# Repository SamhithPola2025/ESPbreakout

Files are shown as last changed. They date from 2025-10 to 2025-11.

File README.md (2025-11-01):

# ESPbreakout
## Overview
ESPbreakout is a breakout board for the popular ESP32-s3  chip that includes many breakout pins, compatible with any other ESP32 setup (for the most part), and has programming via USB 2.0.
This board uses the ESP32-S3 SOC, which means that it does not use any of the modules that espressif has already made, and just the bare ESP32-S3 chip.
This board includes pins for progamming, a USB-C port (for programming & power), a screw terminal to convenient wire up a Lithium battery to (3.7v). And you can also utilize the PSRAM that I added externally onto the board. The board includes comprehensive labels for buttons and pins, for ease of use. The cost and materials used to manafacture/make this board are in the BOM.csv file.

## Intent behind making this board:
I made this board to showcase what I already know, and to learn a lot of new things (I can say that this one was accomplished). I also made this board to act as a substitute for the ESP32-S3 devboard that exists, and of course it wont be better than the board made by the actual company, Espressif, but it will be pretty decent and working!

## Pictures



(Pictures of the built version will be added once I get all the components and solder what needs to be soldered, for the most part this is PCBA though.)

| Reference | Quantity | Part | Unit Price | Extended Price |
| --- | --- | --- | --- | --- |
| PCBA | 1 | PCBA Estimate | $52.55 | $52.55 |
| B1 | 1 | TinyCircuits BATTERY LITH-ION 3.7V 1AH | $9.95 | $9.95 |
| C1 | 1 | Pololu 2PIN F JST PH-STYLE CABLE 12CM | $1.47 | $1.47 |
| J1 | 3 | Sullins Connector Solutions CONN HDR 4POS 0.1 GOLD PCB | $0.38 | $1.14 |
| J2 | 1 | Phoenix Contact TERM BLK 2POS SIDE ENTRY 5MM PCB | $0.78 | $0.78 |
| **Total** | | | | **$71.89** |

Note: $6.00 of buffer is added for shipping or tariff changes. Any unused buffer will be returned.

## Cart screenshots
Screenshot 2025-11-01 at 11 53 29 AM
Screenshot 2025-11-01 at 12 08 29 PM

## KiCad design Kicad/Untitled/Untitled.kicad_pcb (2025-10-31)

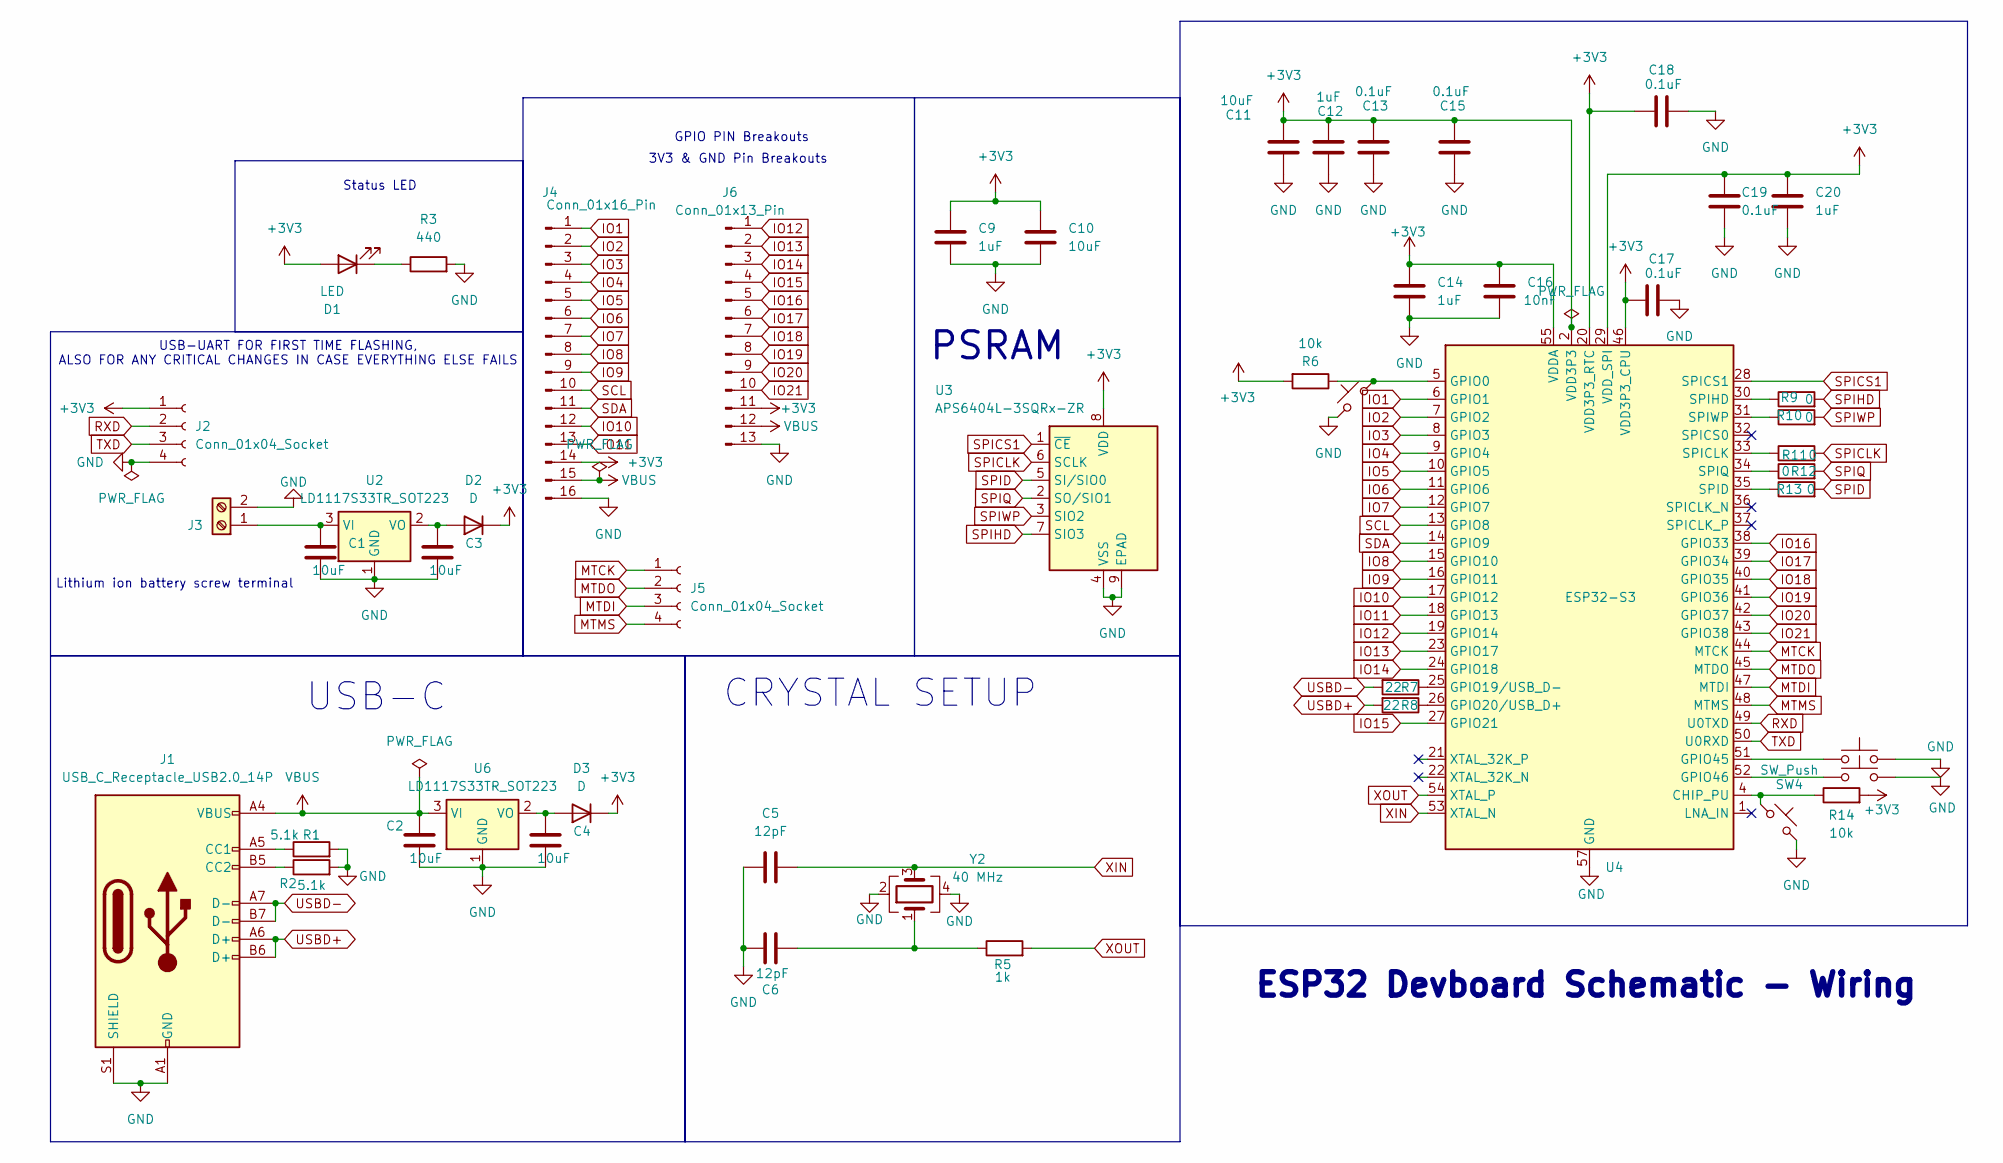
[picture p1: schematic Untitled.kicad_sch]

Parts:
C1, C2, C3, C4, C10, C11: 10uF; C_0402_1005Metric
C5, C6: 12pF; C_0402_1005Metric
C9, C12, C14, C20: 1uF; C_0402_1005Metric
C13, C15, C17, C18, C19: 0.1uF; C_0402_1005Metric
C16: 10nF; C_0402_1005Metric
D1: LED; LED_WS2812B-Mini_PLCC4_3.5x3.5mm
D2, D3: D; D_0402_1005Metric
J1: USB_C_Receptacle_USB2.0_14P; HRO_TYPE-C-31-M-12
J2, J5: Conn_01x04_Socket; PinSocket_1x04_P2.54mm_Horizontal
J3: Screw_Terminal_01x02; TerminalBlock_Phoenix_MKDS-1,5-2-5.08_1x02_P5.08mm_Horizont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
J4: Conn_01x16_Pin; PinHeader_1x16_P2.54mm_Vertical
J6: Conn_01x13_Pin; PinHeader_1x13_P2.54mm_Vertical
R1, R2: 5.1k; R_0402_1005Metric
R3: 440; R_0402_1005Metric
R5: 1k; R_0402_1005Metric
R6, R14: 10k; R_0402_1005Metric
R7, R8: 22; R_0402_1005Metric
R9, R10, R11, R12, R13: 0; R_0201_0603Metric
SW1, SW2: SW_Push_45deg; SW_SPST_B3U-1000P
SW3, SW4: SW_Push; SW_SPST_B3U-1000P
U2, U6: LD1117S33TR_SOT223; SOT-223-3_TabPin2
U3: APS6404L-3SQRx-ZR; Winbond_USON-8-1EP_3x2mm_P0.5mm_EP0.2x1.6mm
U4: ESP32-S3; QFN-56-1EP_7x7mm_P0.4mm_EP4x4mm
Y2: 40 MHz; OSC_CX2016DB40000D0FLJCC

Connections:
+3V3: C9.1, C10.1, C11.2, C12.2, C13.2, C14.1, C15.2, C16.1, C17.1, C18.1, C19.1, C20.1, D1.2 (A), D2.1 (K), D3.1 (K), J2.1, J4.14, J6.11, R6.2, R14.2, U3.8 (VDD), U4.2 (VDD3P3), U4.3 (VDD3P3), U4.20 (VDD3P3_RTC), U4.29 (VDD_SPI), U4.46 (VDD3P3_CPU), U4.55 (VDDA), U4.56 (VDDA)
GND: C1.2, C2.2, C3.2, C4.2, C5.1, C6.1, C9.2, C10.2, C11.1, C12.1, C13.1, C14.2, C15.1, C16.2, C17.2, C18.2, C19.2, C20.2, J1.A1 (GND), J1.A12 (GND), J1.B1 (GND), J1.B12 (GND), J1.S1 (SHIELD), J2.4, J3.2, J4.16, J6.13, R1.2, R2.2, R3.2, SW1.1, SW2.2, SW3.2, SW4.2, U2.1 (GND), U3.4 (VSS), U3.9 (EPAD), U4.57 (GND), U6.1 (GND), Y2.2, Y2.4; also elsewhere on the board
IO1: J4.1, U4.6 (GPIO1)
IO2: J4.2, U4.7 (GPIO2)
IO3: J4.3, U4.8 (GPIO3)
IO4: J4.4, U4.9 (GPIO4)
IO5: J4.5, U4.10 (GPIO5)
IO6: J4.6, U4.11 (GPIO6)
IO7: J4.7, U4.12 (GPIO7)
IO8: J4.8, U4.15 (GPIO10)
IO9: J4.9, U4.16 (GPIO11)
IO10: J4.12, U4.17 (GPIO12)
IO11: J4.13, U4.18 (GPIO13)
IO12: J6.1, U4.19 (GPIO14)
IO13: J6.2, U4.23 (GPIO17)
IO14: J6.3, U4.24 (GPIO18)
IO15: J6.4, U4.27 (GPIO21)
IO16: J6.5, U4.38 (GPIO33)
IO17: J6.6, U4.39 (GPIO34)
IO18: J6.7, U4.40 (GPIO35)
IO19: J6.8, U4.41 (GPIO36)
IO20: J6.9, U4.42 (GPIO37)
IO21: J6.10, U4.43 (GPIO38)
MTCK: J5.1, U4.44 (MTCK)
MTDI: J5.3, U4.47 (MTDI)
MTDO: J5.2, U4.45 (MTDO)
MTMS: J5.4, U4.48 (MTMS)
unnamed: C6.2, R5.1, Y2.1
unnamed: D1.1 (K), R3.1
unnamed 29: C3.1, D2.2 (A), U2.2 (VO); also elsewhere on the board
unnamed: C4.1, D3.2 (A), U6.2 (VO)
unnamed: J1.A5 (CC1), R1.1
unnamed: J1.B5 (CC2), R2.1
unnamed 33: C1.1, J3.1, U2.3 (VI); also elsewhere on the board
unnamed: R14.1, SW2.1, U4.4 (CHIP_PU)
unnamed: R6.1, SW1.2, U4.5 (GPIO0)
unnamed: R7.1, U4.25 (GPIO19/USB_D-)
unnamed: R8.1, U4.26 (GPIO20/USB_D+)
unnamed: SW3.1, U4.51 (GPIO45)
unnamed: SW4.1, U4.52 (GPIO46)
unnamed: R11.1, U4.33 (SPICLK)
unnamed: R13.1, U4.35 (SPID)
unnamed: R9.1, U4.30 (SPIHD)
unnamed: R12.1, U4.34 (SPIQ)
unnamed: R10.1, U4.31 (SPIWP)
RXD: J2.2, U4.49 (U0TXD)
SCL: J4.10, U4.13 (GPIO8)
SDA: J4.11, U4.14 (GPIO9)
SPICLK: R11.2, U3.6 (SCLK)
SPICS1: U3.1 (~CE), U4.28 (SPICS1)
SPID: R13.2, U3.5 (SI/SIO0)
SPIHD: R9.2, U3.7 (SIO3)
SPIQ: R12.2, U3.2 (SO/SIO1)
SPIWP: R10.2, U3.3 (SIO2)
TXD: J2.3, U4.50 (U0RXD)
USBD+: J1.A6 (D+), J1.B6 (D+), R8.2
USBD-: J1.A7 (D-), J1.B7 (D-), R7.2
VBUS: C2.1, J1.A4 (VBUS), J1.A9 (VBUS), J1.B4 (VBUS), J1.B9 (VBUS), J4.15, J6.12, U6.3 (VI)
XIN: C5.2, U4.53 (XTAL_N), Y2.3
XOUT: R5.2, U4.54 (XTAL_P)

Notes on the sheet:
USB-UART FOR FIRST TIME FLASHING, ALSO FOR ANY CRITICAL CHANGES IN CASE EVERYTHING ELSE FAILS
CRYSTAL SETUP
GPIO PIN Breakouts
Status LED
Lithium ion battery screw terminal
3V3 & GND Pin Breakouts
USB-C
ESP32 Devboard Schematic - Wiring
PSRAM

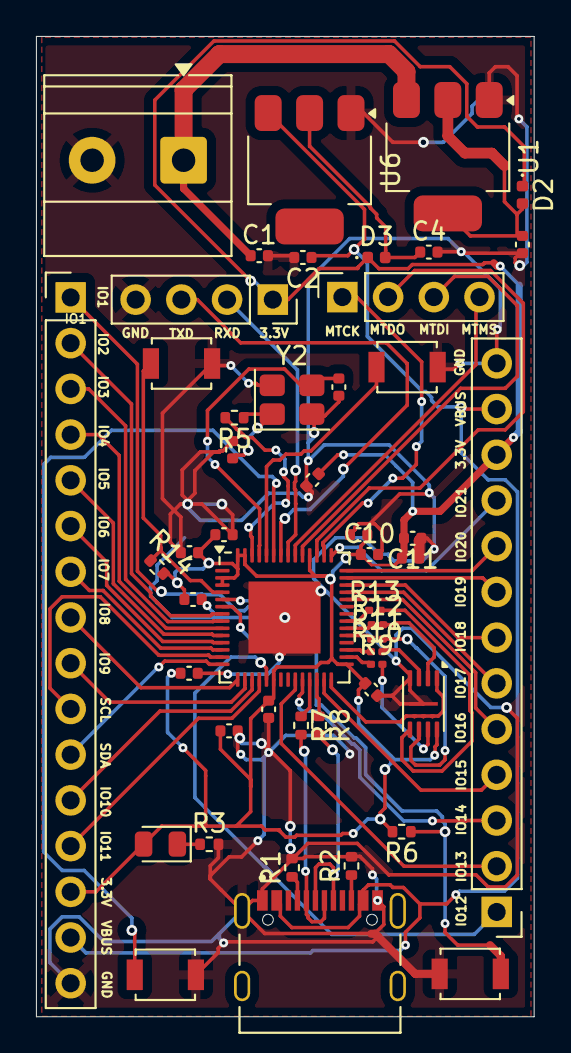
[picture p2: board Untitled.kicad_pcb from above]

Board: 2 copper layers, 27.7 x 54.5 mm, 49 parts (0 on the bottom side), 60 nets.

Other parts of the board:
U1: NCP1117-3.3_TO252; SOT-223-3_TabPin2

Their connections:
GND: U1.1 (GND); also elsewhere on the board
unnamed 29: U1.2 (VO); also elsewhere on the board
unnamed 33: U1.3 (VI); also elsewhere on the board

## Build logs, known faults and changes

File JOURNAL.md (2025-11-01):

<!--
  ===================    !!READ THIS NOTICE!!   ====================
  DO NOT edit this file manually. Your changes WILL BE OVERWRITTEN!
  This journal is auto generated and updated by Hack Club Blueprint.
  To edit this file, please edit your journal entries on Blueprint.
  ==================================================================
-->

## 10/16/2025 - Wired some basic connections + did the USB-C wiring  

Screenshot 2025-10-16 at 7.55.04 PM.png

Screenshot 2025-10-16 at 8.04.58 PM.png

I added the main chip, wired some basic connections on the main chip itself, but I also added some stuff related to USB-C, infact that is what I spent most of this time on. I also wired up some basic pin headers, might need to change that in the future, but that is some progress. I also took some more time to make sure all of my connections were good; that is important for a devboard.  

## 10/20/2025 - Added some more gpios, added some basic wiring for the power  



I wired up more GPIO pins, I cant figure out how to do the power pins so in the meanwhile I asked some people on the slack and while they were responding I added a screw terminal and added some capacitors. I also refurbished the schematic section for the other crystal.  

## 10/21/2025 - Wired important pins on main chip, USB-UART and GPIO's  




I spent a good chunk of my time today just looking through docs to wire some important pins on the main chip right, because if I dont I could have issues with booting it up. I also added some more GPIO's to the headers and ill do power pins tommorow. I added USB-UART and added a stepdown for my battery input from 3.7v to 3.3v, with capacitors ofc to smoothen out the signal.  

## 10/24/2025 - Cleaned up schematic, wired PSRAM, wired power pins.  



Today I spent a LONG while figuring out how to do the power pins after scraping the internet and my friends for a while. I also took a good chunk of time to wire the PSRAM which is the external RAM that im adding that can be accessed at any time. I also took a lot of time to clean up the schematic formatting AND I did a lot of minor changes like adding some more resistors, inductors capacitors and fixing some wiring where it was needed.

Tommorow the schematic should be done!  

## 10/25/2025 - Finalizing schematic, assigning footprints and designing.  



Today, I took a while to finalize my schematic and send it to some more knowledgable people, and the KiCad discord. Then I spent a long time getting the correct footprints for each parts. And then the main chunk of this time was spend starting with the routing, I got pretty far but I have to figure out something better for the capacitors, as space is limited, I think that wont be too much of a problem however. (note to self: find a better footprint for the usb-c)  

## 10/26/2025 - Rerouted pcb, chose configuration  

Today was entirely a PCB design day, I had to redo the design twice and mess with a bunch of traces for hours on end to get this to fit and work nicely, but now I have a issue with vias that I dont feel like fixing now, that can wait for tommorow as I still need to figure out the proper fix for it. I also spend a substantial amount of time figuring out the best way to put all the components.



## 10/31/2025 - Did FINALIZATIONS, added BOM, and rerouted 4 times  

Yes, call me crazy for rerouting this that many times but I want this to be as good as possible and obviously want it to work. So I rerouted completely and added a BOM, I uploaded to JLCPCB, spent a lot of time fiddling with parts to get cheapest options, fiddled around with positions to make sure it would work (my position file was really weird for some reason). I sent this over to the KiCad discord server and I also sent it over to some people on the slack for review, so this was mostly just a revising session. I had to do some math to figure out if things would work regarding resistance and capacitance, I also took some time to find an appropriate lithium ion battery.





## 11/1/2025 - Changed prices & redid pcba order.  



After spending a little bit of time revising this, I got the price of the PCBA to be pretty much halved, now the price should be good to go! I also updated the BOM.csv and the BOM in the Readme.md.

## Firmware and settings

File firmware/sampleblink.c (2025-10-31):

#include "freertos/FreeRTOS.h"
#include "freertos/task.h"
#include "driver/gpio.h"

#define LED_PIN 2

void blink_task(void *pvParameter) {
    gpio_pad_select_gpio(LED_PIN);
    gpio_set_direction(LED_PIN, GPIO_MODE_OUTPUT);
    while(1) {
        gpio_set_level(LED_PIN, 1);
        vTaskDelay(500 / portTICK_PERIOD_MS);
        gpio_set_level(LED_PIN, 0);
        vTaskDelay(500 / portTICK_PERIOD_MS);
    }
}

void app_main(void) {
    xTaskCreate(blink_task, "blink_task", 2048, NULL, 5, NULL);
}

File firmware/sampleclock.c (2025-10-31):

#include "freertos/FreeRTOS.h"
#include "freertos/task.h"
#include "driver/gpio.h"
#include "driver/timer.h"

#define LED_PIN 2 

void IRAM_ATTR timer_isr(void *arg) {
    gpio_set_level(LED_PIN, !gpio_get_level(LED_PIN)); // i hope thats how it works sob
    TIMERG0.int_clr_timers.t0 = 1;                     
}

void app_main(void) {
    // setup LED pin
    gpio_pad_select_gpio(LED_PIN);
    gpio_set_direction(LED_PIN, GPIO_MODE_OUTPUT);

    // configure timer 0
    timer_config_t config = {
        .divider = 80,       // 80 MHz / 80 = 1 MHz timer
        .counter_dir = TIMER_COUNT_UP,
        .counter_en = TIMER_PAUSE,
        .alarm_en = TIMER_ALARM_EN,
        .auto_reload = true
    };
    timer_init(TIMER_GROUP_0, TIMER_0, &config);
    timer_set_alarm_value(TIMER_GROUP_0, TIMER_0, 1000000); // 1 second
    timer_enable_intr(TIMER_GROUP_0, TIMER_0);
    timer_isr_register(TIMER_GROUP_0, TIMER_0, timer_isr, NULL, ESP_INTR_FLAG_IRAM, NULL);
    timer_start(TIMER_GROUP_0, TIMER_0);

    while (1) {
        vTaskDelay(1000 / portTICK_PERIOD_MS); // optional, main loop idle
    }
}

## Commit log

2025-10-17 Added basic USBC stuff in schematic, set up some basic pins on the board and started to organize wiring.
    [Untitled.kicad_pcb, Untitled.kicad_sch]
2025-10-17 update schematic, more info in journakl
    [Untitled.kicad_sch]
2025-10-18 Add BOM.csv with component details
    [BOM.csv]
2025-10-22 journal entry explains
    [Untitled.kicad_sch]
2025-10-25 journal update
    [Untitled.kicad_sch]
2025-10-29 pcb update
    [Untitled.kicad_pcb, Untitled.kicad_sch]
2025-10-31 Fix duplicate entry for J2 in BOM.csv
    Removed duplicate entry for J2 in BOM.
    [BOM.csv]
2025-10-31 Fix quantity for J2 in BOM.csv
    [BOM.csv]
2025-10-31 Update J2 quantity in BOM.csv
    [BOM.csv]
2025-10-31 Fix formatting of total price in BOM.csv
    [BOM.csv]
2025-10-31 Rename PCB Estimate to PCBA Estimate in BOM.csv
    [BOM.csv]
2025-10-31 Enhance README with overview and images
    Updated the README to provide a detailed overview of the ESPbreakout board, including its features, intent, and images.
2025-10-31 Adjust PCBA extended price and total in BOM.csv
    Updated the extended price for PCBA and total cost.
    [BOM.csv]
2025-10-31 journal update, pcb update
    [Untitled.kicad_pcb, Untitled.kicad_sch]
2025-10-31 sample firmware added
2025-11-01 Update BOM.csv with new pricing and total calculation
    [BOM.csv]
